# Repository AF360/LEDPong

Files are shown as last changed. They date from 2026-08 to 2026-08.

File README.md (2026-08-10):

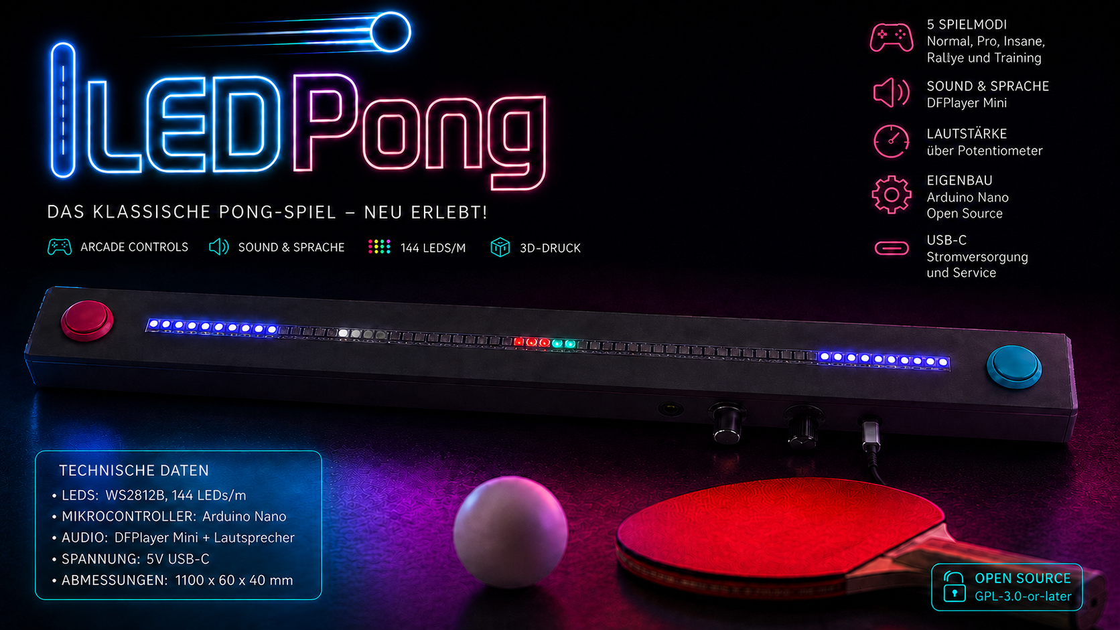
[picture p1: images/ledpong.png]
LEDPong


# LEDPong

LEDPong ist eine moderne Interpretation des klassischen Pong-Spiels.
Gespielt wird nicht auf einem Bildschirm, sondern auf einem **1 m langen LED-Strip mit 144 adressierbaren WS2812B-LEDs**.

Zwei Spieler versuchen, den als leuchtende LED dargestellten Ball mit ihren Arcade-Tastern im richtigen Moment zurückzuspielen. Mehrere Schwierigkeitsstufen und Spielmodi, Sprachansagen, Soundeffekte und eine Lautstärkeregelung ergänzen das Spiel.

## Spielmodi

1. **Anfänger-Modus** (große Rückschlagzonen, niedrige Geschwindigkeit und Beschleunigung)
2. **Profi-Modus** (kleinere Rückschlagzonen, höhere Geschwindigkeit und Beschleunigung)
3. **Insane-Modus** (stark verkleinerte Rückschlagzonen und höhere Beschleunigug)
4. **Rallye-Modus** (nach jeweils drei erfolgreichen Rückschlägen werden beide Rückschlagzonen verkleinert)
5. **Training-Modus** (ein Spieler tritt auf der grünen Seite gegen den Arduino an)

## Besonderheiten

- 🎮 Zwei Arcade-Taster für die Spieler
- 🔊 Sprachansagen und Soundeffekte über DFPlayer Mini
- 🌈 144 adressierbare WS2812B-LEDs
- 🎚 Lautstärkeregelung per Potentiometer
- 🎛 5-fach-Moduswahlschalter zur Auswahl fünf unterschiedlicher Spielmodi
- 🖨 Druckfertige 3D-Modelle für Gehäuse- und Bedienelemente
- 🔧 Vollständige Aufbau-, Verdrahtungs- und Bedienungsdokumentation

## Dokumentation und Dateien

- **[Dokumentation](docs/README.md)** – Stückliste, Aufbauanleitung, Verdrahtungsplan und Bedienungsanleitung
- **[Firmware](firmware/README.md)** – Arduino-Sketch und benötigte Bibliotheken
- **[Audiodateien](audio/README.md)** – Sprachansagen und Soundeffekte
- **[Gehäuse und 3D-Druck](gehäuse/README.md)** – Hinweise zum Kabelkanal und zu den STL-Dateien
- **[Release V1.1.1](https://github.com/AF360/LEDPong/releases/tag/V1.1.1)** – aktueller, stabiler und vollständiger Veröffentlichungsstand

## Lizenz und Danksagungen

LEDPong wird unter der **GNU General Public License v3.0 oder später** veröffentlicht.
Weitere Informationen zu den ursprünglichen Projekten und Mitwirkenden befinden sich in **[AUTHORS.md](AUTHORS.md)**.

### Das fertige LEDPong, hier als weiße Version mit 144er Light-Strip:
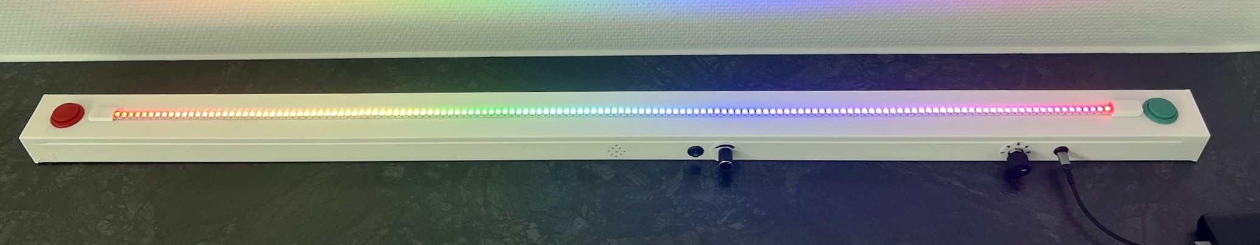
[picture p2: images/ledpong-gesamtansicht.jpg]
LEDPong1

Gesamtansicht, LED-Rainbow während des Systemstarts

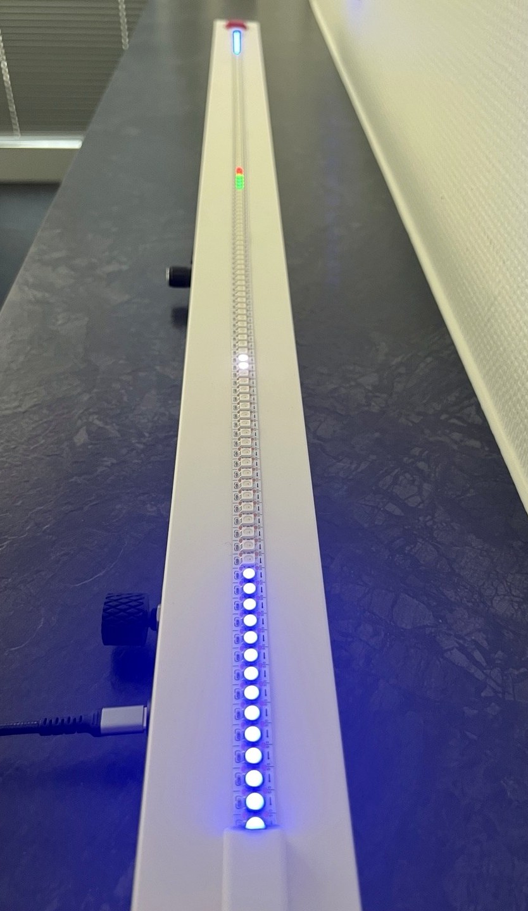
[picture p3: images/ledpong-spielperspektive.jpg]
LEDPong2

Spielperspektive mit Rückschlagzone, Ball in Bewegung und Score-Anzeige in der Mitte

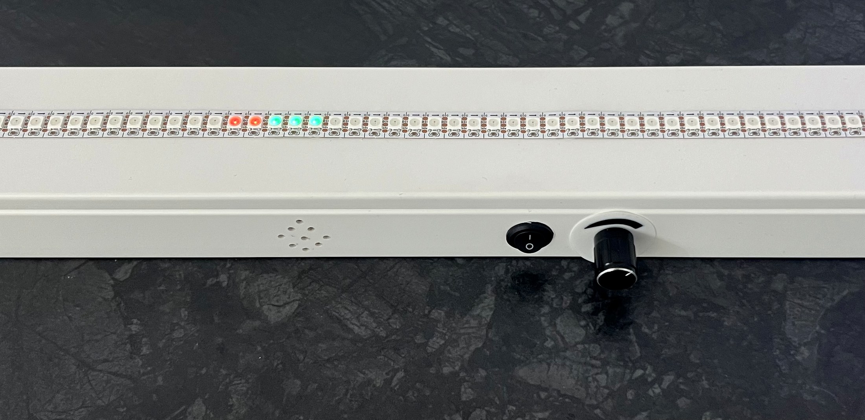
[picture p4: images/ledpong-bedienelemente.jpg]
LEDPong3

Score-Anzeige und Lautstärke-Regler sowie LS-Ein-/Ausschalter

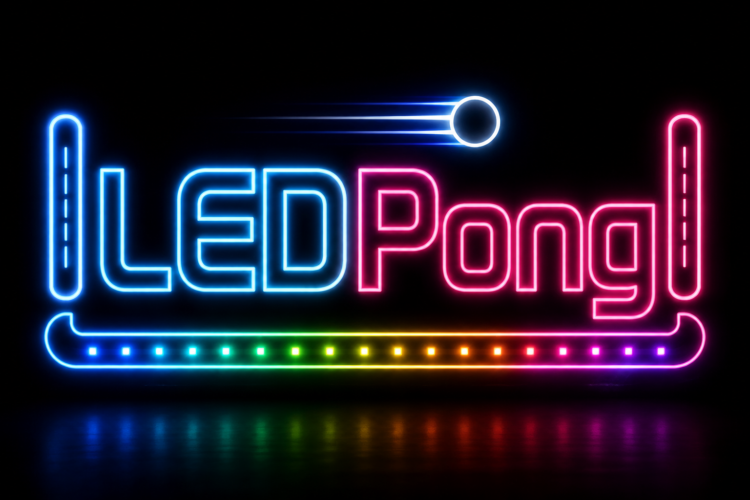
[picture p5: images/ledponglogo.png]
LEDPong-Logo


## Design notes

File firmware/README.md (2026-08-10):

# Firmware

Für den LEDPong-Sketch (LEDPong_v1.1.0.ino) müssen zusätzliche folgende Arduino-Bibliotheken in der Arduino-IDE installiert werden:

- FastLED by Daniel Garcia (verwendet: Version 3.10.5)
- DFRobotDFPlayerMini by DFRobot (verwendet: Version 1.0.6)

## Spielerfarben anpassen

Standardmäßig verwendet LEDPong **Rot** für Spieler 1 und **Grün** für Spieler 2. Die Farben werden im Sketch über folgende Zeile festgelegt:

```cpp
byte playerColor[] = {0, 96};    // Rot & Grün
```

Die Werte entsprechen dem Farbton (`Hue`) des von FastLED verwendeten HSV-Farbmodells. Einige geeignete Beispiele:

| Farbe | Wert |
|---|---:|
| Rot | `0` |
| Gelb | `64` |
| Grün | `96` |
| Hellblau / Türkis | `128` |
| Blau | `160` |
| Violett | `192` |

Beispiel für **Gelb und Hellblau**:

```cpp
byte playerColor[] = {64, 128};
```

Die Rückschlagzonen verwenden standardmäßig den Wert `160` (Blau). Dieser Farbwert sollte daher möglichst **nicht als Spielerfarbe** verwendet werden, damit Spieler- und Rückschlagzonen eindeutig unterscheidbar bleiben.

Werden andere Tastenfarben verwendet, können zusätzlich die entsprechenden alternativen Sprachansagen aus dem Verzeichnis `audio/alternative-Tastenfarben` verwendet werden.

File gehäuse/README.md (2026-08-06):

# Gehäuse und 3D-Druck

Als Gehäuse wird ein handelsüblicher 2 m Kabelkanal mit den Massen 60 x 40 mm verwendet und auf ca. 1100-1150 mm abgelängt.
Bezugsquelle z.B. https://www.bauhaus.info/kabelkanaele/kabelkanal/p/22835297 (in Baumärkten meistens nur in weiß oder grau erhältlich)
oder bei Amazon auch in schwarz: https://www.amazon.de/dp/B0F6V747F6 
(Aufpassen: Bei Amazon werden häufig 2x 1M Stücke angeboten, wir brauchen aber mindestens 1,10 Meter am Stück!)

Die .STL-Dateien für passende Endkappen, LED-Abdeckkappen sowie Wahlschalter-Kappe & Skalen befinden sich im Unterordner "stl"

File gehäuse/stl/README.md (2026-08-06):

# STL-Dateien

In diesem Verzeichnis befinden sich die druckfertigen 3D-Modelle für LEDPong.

- **[Endkappe 60 × 40 mm, geschlossen](LEDPong-Endkappe-60x40.stl)**  
  Geschlossene Endkappe für das gegenüberliegende Ende des Kabelkanals.

- **[Endkappe 60 × 40 mm mit USB-C-Einlass](LEDPong-Endkappe-mit-USB-60x40.stl)**  
  Endkappe zur Aufnahme der USB-C-Panelbuchse.

- **[Abdeckkappe für die Enden des LED-Strips](LEDStrip-Abdeckkappe.stl)**  
  Verdeckt die Anschlussleitungen und Bohrungen an den Enden des LED-Strips. Das Modell wird für beide Seiten verwendet.

- **[Zeigerknopf für den Moduswahlschalter](Modusauswahlknopf-mit-Zeiger.stl)**  
  Drehknopf mit Zeiger zur Auswahl der fünf Spielmodi.

- **[Schalttafel für die Modusauswahl 1–5](Schalttafel-1-2-3-4-5.stl)**  
  Beschriftete Skala für den 5-fach-Moduswahlschalter.

- **[Schalttafel für die Lautstärke](Schalttafel-Lautstärke.stl)**  
  Beschriftete Skala für das Lautstärke-Potentiometer.

## Druckhinweise

Die Bauteile können mit gängigen Filamenten wie **PLA** oder **PETG** gedruckt werden.

Für die zweifarbigen Schalttafeln kann während des Drucks ein Filamentwechsel vorgenommen oder ein Mehrfarbdrucksystem verwendet werden.

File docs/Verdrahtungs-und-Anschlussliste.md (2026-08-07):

# LEDPong Verdrahtung 

## Arduino Nano

| Nano-Pin | Ziel | Elektrische Funktion |
|---|---|---|
| 5V | gemeinsamer geregelter +5V-Bus | Versorgung |
| GND | gemeinsamer GND-Bus | Masse |
| D2 | Taster Spieler 0 → GND | `INPUT_PULLUP`, aktiv LOW |
| D3 | Taster Spieler 1 → GND | `INPUT_PULLUP`, aktiv LOW |
| D4 | DFPlayer TX | SoftwareSerial RX des Nano |
| D5 | über 1 kΩ zu DFPlayer RX | SoftwareSerial TX des Nano |
| D6 | WS2812B DIN | LED-Datensignal |
| D7 | Drehschalter Position 1 → GND über COM | Modus Normal, aktiv LOW |
| D8 | Drehschalter Position 2 → GND über COM | Modus Pro, aktiv LOW |
| D9 | Drehschalter Position 3 → GND über COM | Modus Insane, aktiv LOW |
| D10 | Drehschalter Position 4 → GND über COM | Modus Rallye, aktiv LOW |
| D11 | Drehschalter Position 5 → GND über COM | Modus Training, aktiv LOW |
| A0 | unbeschaltet | Rauschquelle für `randomSeed(analogRead(0))` |
| A1 | Schleifer des 10-kΩ-Potis | Lautstärke; GND = Minimum, +5V = Maximum |

## DFPlayer Mini

| DFPlayer-Pin | Ziel |
|---|---|
| VCC | +5V |
| GND | gemeinsamer GND |
| TX | Nano D4 |
| RX | Nano D5 über 1 kΩ Serienwiderstand |
| SPK+ | über SPST-Ein/Aus-Schalter zum Lautsprecher + |
| SPK− | direkt zum Lautsprecher − |

Der Lautsprecherausgang ist gebrückt. Weder SPK+ noch SPK− darf mit GND verbunden werden.

## WS2812B-Strip

- 1 Meter, 144 LEDs (`NUM_LEDS = 144`)
- +5V an geregelte 5V-Versorgung
- GND an gemeinsame Masse
- DIN an Nano D6 (Achtung: Die WS2812B Strips haben eine Datenrichtung! Der Anschluss des Arduino muss am Eingang des Strips erfolgen.)
- Stromversorgung passend zur tatsächlichen Helligkeit dimensionieren

## Bedienelemente

- Spieler-0-Taster: Nano D2 ↔ Taster ↔ GND
- Spieler-1-Taster: Nano D3 ↔ Taster ↔ GND
- 5-fach-Drehschalter: Positionen 1–5 an D7–D11, gemeinsamer Anschluss COM an GND
- Lautstärke-Poti 10 kΩ: Endanschlüsse an GND und +5V, Schleifer an A1
- Speaker-Mute: SPST-Schalter in Reihe zwischen DFPlayer SPK+ und Lautsprecher+

## Versorgung

- Eine gemeinsame geregelte +5V-Quelle
- Gemeinsame Masse für Nano, DFPlayer, LED-Strip, Taster, Drehschalter und Poti
- 100 nF und 100 µF parallel zwischen +5V und GND nahe der Steuerelektronik
- Externe +5V an den 5V-Pin des Nano, nicht an VIN
- Keine zweite USB-Stromquelle gleichzeitig anschließen

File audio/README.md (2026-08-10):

# Audiodateien

Die mit LEDPong ausgelieferten Sprachansagen und Soundeffekte wurden speziell für dieses Projekt erstellt.
Die Audiodateien können bei Bedarf auch durch eigene Dateien ersetzt werden. Damit die Firmware weiterhin funktioniert, müssen die Dateinamen und die Ordnerstruktur dabei unverändert bleiben.

## Aktuelle Belegung

| Datei | Verwendung | gesprochener Text |
|---|---|---|
| 001.mp3 | Spiel beginnt | |
| 002.mp3 | Ball getroffen | |
| 003.mp3 | Ball verfehlt | |
| 004.mp3 | Aufschlag | |
| 005.mp3 | Spiel gewonnen | |
| 010.mp3 | Begrüßung | "Hallo. Willkommen zu Pong" |
| 011.mp3 | Bedienhinweis | "Helligkeit mit roter Taste einstellen" |
| 012.mp3 | Bedienhinweis | "Spiel mit grüner Taste starten" |
| 020.mp3 | Modus Normal | "Du hast den Anfänger-Modus ausgewählt" |
| 021.mp3 | Modus Pro | "Du hast den Profi-Modus ausgewählt" |
| 022.mp3 | Modus Insane | "Du hast den Insane-Modus ausgewählt" |
| 023.mp3 | Rallye-Modus | "Du hast den Rallye-Modus ausgewählt" |
| 024.mp3 | Training-Modus | "Du hast den Training-Modus ausgewählt" |

## Ordnerstruktur auf der microSD-Karte
Die Firmware erwartet dreistellig nummerierte Dateien im Ordner `01` der microSD-Karte des DFPlayerMini.

```text
01/
├── 001.mp3
├── 002.mp3
├── 003.mp3
├── 004.mp3
├── 005.mp3
├── 010.mp3
├── 011.mp3
├── 012.mp3
├── 020.mp3
├── 021.mp3
├── 022.mp3
├── 023.mp3
└── 024.mp3
```

## Alternative Hinweisdateien für andere Tastenfarben

| Datei | Verwendung | gesprochener Text |
|---|---|---|
| 011-gelb.mp3 | Bedienhinweis | "Helligkeit mit gelber Taste einstellen" |
| 011-gruen.mp3 | Bedienhinweis | "Helligkeit mit grüner Taste einstellen" |
| 011-blau.mp3 | Bedienhinweis | "Helligkeit mit blauer Taste einstellen" |
| 012-gelb.mp3 | Bedienhinweis | "Spiel mit gelber Taste starten" |
| 012-blau.mp3 | Bedienhinweis | "Spiel mit blauer Taste starten" |
| 012-rot.mp3 | Bedienhinweis | "Spiel mit roter Taste starten" |

### Andere Tasten- und Spielerfarben verwenden

Die Farbe der Arcade-Taster und die Spielerfarben der LEDs sind technisch unabhängig voneinander. Werden andere Tasterfarben als Rot und Grün verwendet, müssen daher zwei Dinge angepasst werden:

1. Die gewünschten LED-Spielerfarben im Sketch über `playerColor[]` einstellen, siehe dazu auch [Firmware/README.md](/firmware/README.md).
2. Die passenden Sprachansagen aus `audio/alternative-Tastenfarben` auswählen und als `011.mp3` bzw. `012.mp3` auf die microSD-Karte kopieren.

Beispiel für einen **gelben linken Taster** und einen **blauen rechten Taster**:

```cpp
byte playerColor[] = {64, 128};    // Gelb & Hellblau
```

Dazu:

- `011-gelb.mp3` als `011.mp3` auf die Speicherkarte kopieren.
- `012-blau.mp3` als `012.mp3` auf die Speicherkarte kopieren.

Für den rechten Spieler wird im Beispiel bewusst der Farbwert `128` (Hellblau/Türkis) verwendet. Dadurch bleibt die Spielerfarbe deutlich von den blauen Rückschlagzonen mit dem Farbwert `160` unterscheidbar, obwohl physisch ein blauer Arcade-Taster verwendet wird.

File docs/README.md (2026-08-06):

# Dokumentation

In diesem Verzeichnis befinden sich alle Unterlagen für den Aufbau, die Verkabelung und die Bedienung von LEDPong.

- **[Stückliste](Stückliste.md)**  
  Übersicht aller benötigten elektronischen, mechanischen und gedruckten Komponenten.

- **[Aufbauanleitung](Aufbauanleitung.md)**  
  Schrittweise Anleitung zur Vorbereitung, Montage, Verkabelung und Inbetriebnahme.

- **[Grafischer Verdrahtungs- und Anschlussplan](Grafischer-Verdrahtungs-und-Anschlussplan.jpg)**  
  Anschlussplan als direkt betrachtbare Grafikdatei.

- **[Bearbeitbarer Verdrahtungs- und Anschlussplan](Grafischer-Verdrahtungs-und-Anschlussplan.drawio)**  
  Quelldatei des Anschlussplans im Draw.io-Format. Sie kann mit [draw.io](https://www.drawio.com) oder der Draw.io-Desktop-App geöffnet und bearbeitet werden.

- **[Verdrahtungs- und Anschlussliste](Verdrahtungs-und-Anschlussliste.md)**  
  Übersicht aller Leitungsverbindungen, Pins und Anschlüsse.

- **[Bedienungsanleitung](Bedienungsanleitung.md)**  
  Beschreibung der Bedienelemente, Spielmodi und Spielregeln.

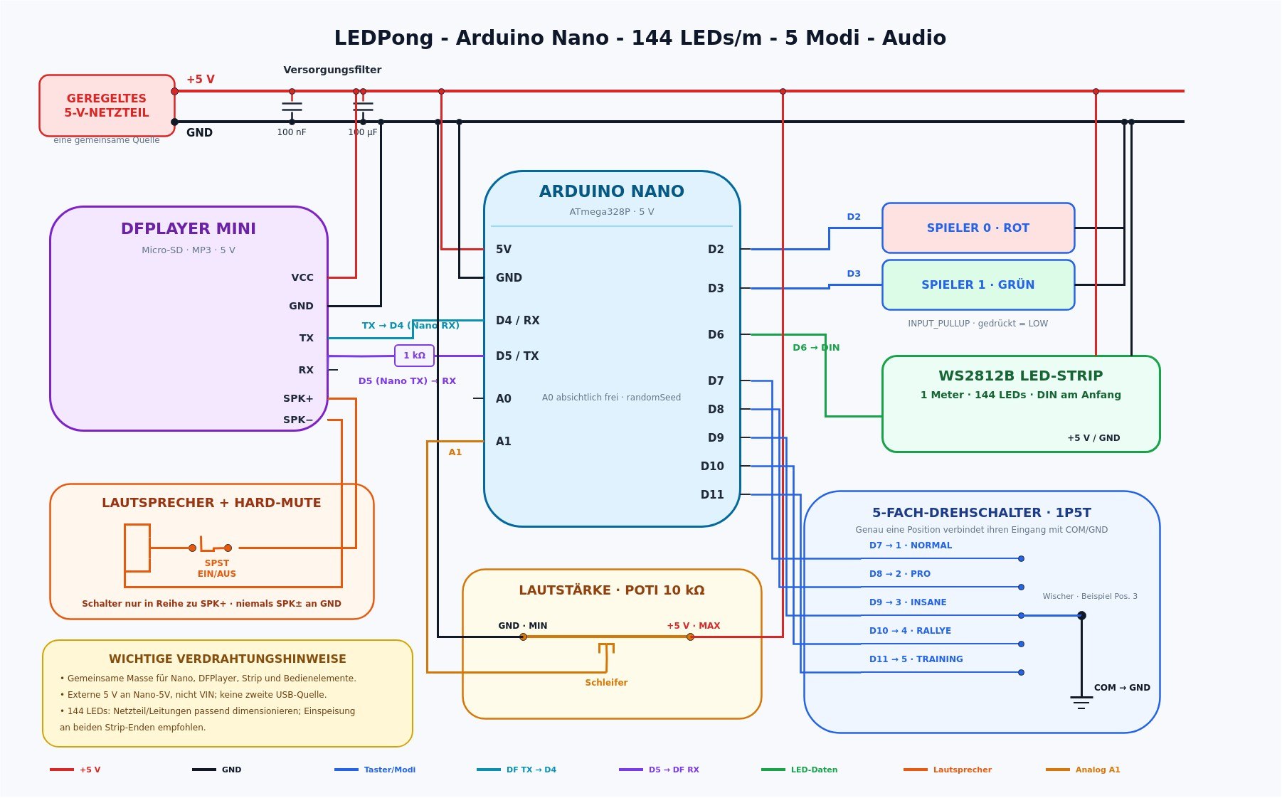
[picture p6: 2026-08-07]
docs/Grafischer-Verdrahtungs-und-Anschlussplan.jpg

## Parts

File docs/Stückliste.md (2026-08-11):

# Stückliste (Bill of Materials)

## Elektronik

  ---------------------------------------------------------------------------------------------------
             Menge Bauteil                     Bezugsquelle                          Einzelpreis
  ---------------- --------------------------- ------------------------------------- ----------------
                1× Arduino Nano V3             https://www.amazon.de/dp/B0GSJCL116   EUR 4,49
                   (ATmega328P, CH340)         

                1× DFPlayer Mini MP3-Modul     https://www.amazon.de/dp/B0DGPW88GF   EUR 3,37

                1× MicroSDHC-Karte 4 GB (für   https://www.amazon.de/dp/B008X6A3WS   EUR 4,90
                   Sprachansagen und Sounds)   

                1× Mini-Lautsprecher, 3 W / 8  https://www.amazon.de/dp/B09PL6XFHB   EUR 1,90
                   Ω                           

                1× WS2812B LED-Strip, 144      https://www.amazon.de/dp/B09N97D1J3   EUR 14,99
                   LEDs/m, 1 m (schwarz)       

                   alternativ: WS2812B         https://www.amazon.de/dp/B09N992SZC   EUR 13,99
                   LED-Strip, 144 LEDs/m, 1 m                                        (alternativ)
                   (weiß)                      

                1× Drehpotentiometer 10 kΩ     https://www.amazon.de/dp/B093DRBG3X   EUR 0,99
                   linear                      

                1× 5-Positionen-Drehschalter   https://www.amazon.de/dp/B0DM5TKYP9   EUR 3,15
                   (1-polig)                   

                2× Arcade-Taster Ø30 mm (1×    https://www.amazon.de/dp/B01MRWL6DW   EUR 1,00
                   rot, 1× grün)                                                     (2 Stück benötigt)

                1× USB-C-Einbaubuchse          https://www.amazon.de/dp/B0F2SFVNQT   EUR 0,77
                   (2-polig) für               
                   Stromversorgung             

                1× USB-C 3.0                   https://www.amazon.de/dp/B0FSPYQZTW   EUR 9,99
                   Panel-Mount-Verlängerung    
                   (Arduino-Serviceport)       

                1× 2-poliger Wippschalter      https://www.amazon.de/dp/B0H68W68SG   EUR 0,70
                   (Lautsprecher Ein/Aus)      
    ---------------------------------------------------------------------------------------------------

## Passive Bauteile

  --------------------------------------------------------------------------------------------------
             Menge Bauteil                 Bezugsquelle                               Einzelpreis
  ---------------- ----------------------- ---------------------------------------------------------
                1× Widerstand 1 kΩ         https://www.amazon.de/gp/aw/d/B0G8F2S5DW   EUR 0,06

                1× Elektrolytkondensator   https://www.amazon.de/dp/B0FB8Y5HYT        EUR 0,26
                   100 µF                  

                1× Keramikkondensator      https://www.amazon.de/Monolithische-       EUR 0,05
                   100 nF                  Mehrschichtiger-Kondensatoren-
                                           verschiedene-elektronische/dp/B0GWMVTD1H
  --------------------------------------------------------------------------------------------------

## Gehäuse

  --------------------------------------------------------------------------------------------------
             Menge Bauteil                 Bezugsquelle                            Einzelpreis
  ---------------- ----------------------  --------------------------------------- -----------------
                1× Kabelkanal 60 × 40 mm,  https://www.bauhaus.info/kabelkanaele/  EUR 4,85
                   Länge ca. 1100 mm       kabelkanal/p/22835297
                   (weiß)                 

                   alternativ: Kabelkanal https://www.amazon.de/dp/B0F6V747F6      EUR 14,90
                   60 × 40 mm (schwarz)                                            (alternativ)
  --------------------------------------------------------------------------------------------------

## Zusätzlich benötigt

-   3D-gedruckte Bauteile (Endkappen, Drehknopf, Modus-Skala, Einleger
    usw.)
-   Litze (empfohlen AWG20 bis AWG18 für die Spannungsversorgung)
-   Lötzinn
-   Lötkolben
-   Schrumpfschlauch
-   Kabelbinder oder Klebepads (optional)
-   Schrauben für Lautsprecher und Befestigungsteile
-   USB-C-Netzteil oder Powerbank (5V, mindestens 3A empfohlen)

## Gesamtkosten

Je nach Bezugsquelle liegen die Materialkosten bei ungefähr **50
€**, sofern Werkzeug und 3D-Drucker bereits vorhanden sind.

> **Hinweis:** Die genannten Bezugsquellen dienen lediglich als
> Beispiele. Gleichwertige oder kompatible Komponenten anderer
> Hersteller können selbstverständlich ebenfalls verwendet werden.

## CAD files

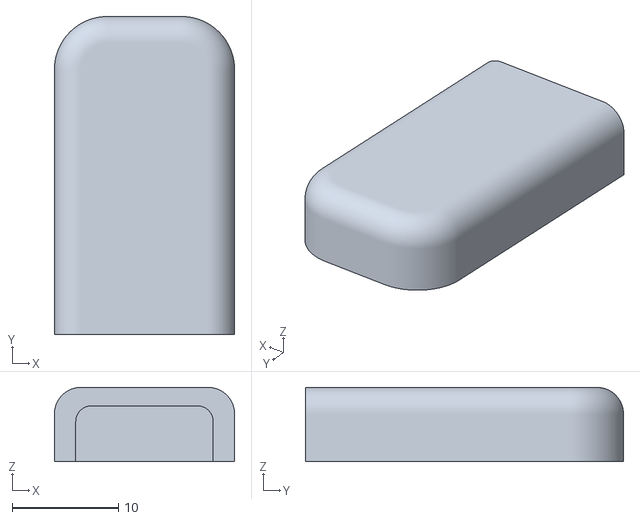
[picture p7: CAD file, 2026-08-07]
gehäuse/stl/LEDStrip-Abdeckkappe.stl
17.0 x 30.0 x 7.00

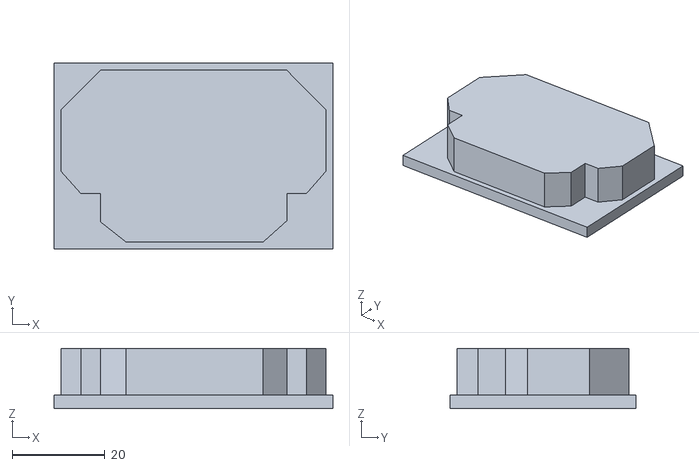
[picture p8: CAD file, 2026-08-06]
gehäuse/stl/LEDPong-Endkappe-60x40.stl
60.0 x 40.0 x 13.0

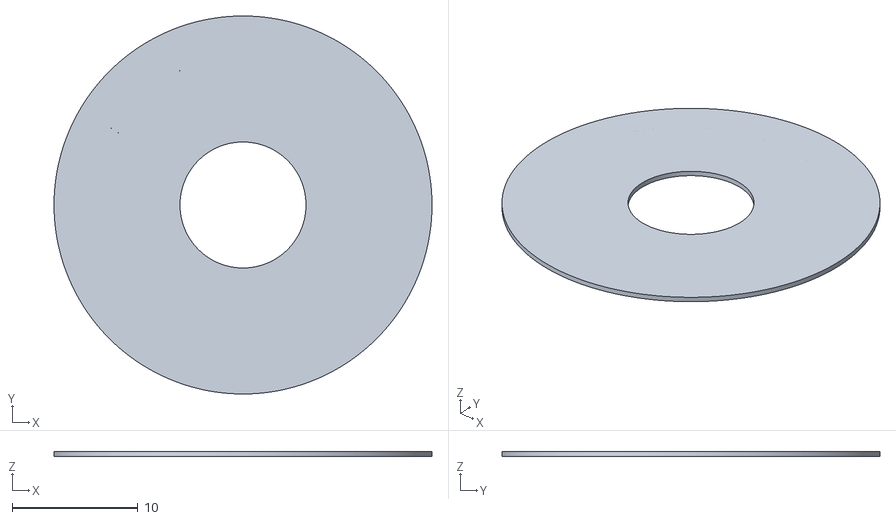
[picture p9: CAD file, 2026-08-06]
gehäuse/stl/Schalttafel-Lautstärke.stl
30.0 x 30.0 x 0.4

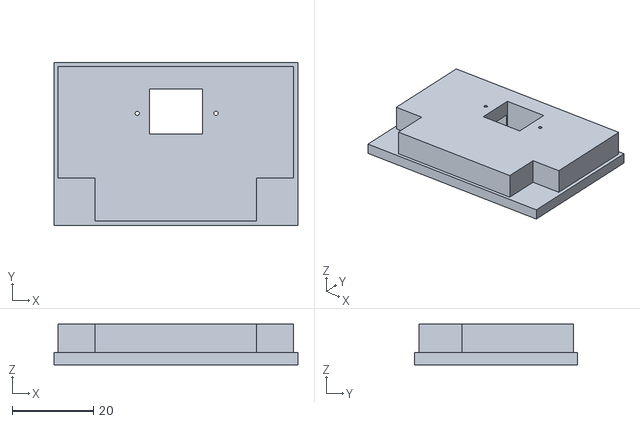
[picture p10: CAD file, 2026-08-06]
gehäuse/stl/LEDPong-Endkappe-mit-USB-60x40.stl
60.0 x 40.0 x 10.0

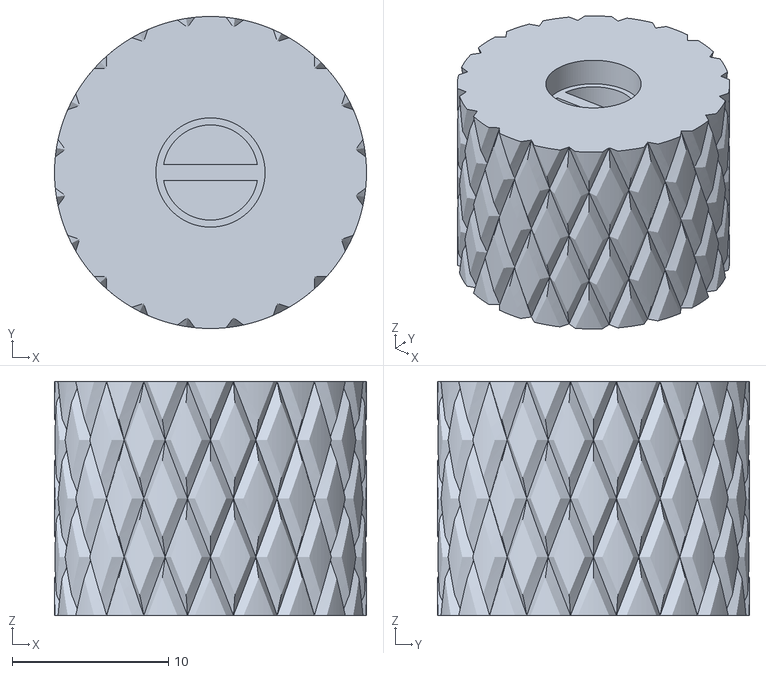
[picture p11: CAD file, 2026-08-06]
gehäuse/stl/Modusauswahlknopf-mit-Zeiger.stl
20.0 x 20.0 x 15.0

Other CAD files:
gehäuse/stl/Schalttafel-1-2-3-4-5.stl

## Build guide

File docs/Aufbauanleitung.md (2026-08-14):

# LEDPong Aufbauanleitung

## 1. Komponenten vorbereiten

Alle benötigten Komponenten und Werkzeuge gemäß Stückliste bereitlegen und die benötigten 3D-Druckteile ausdrucken.
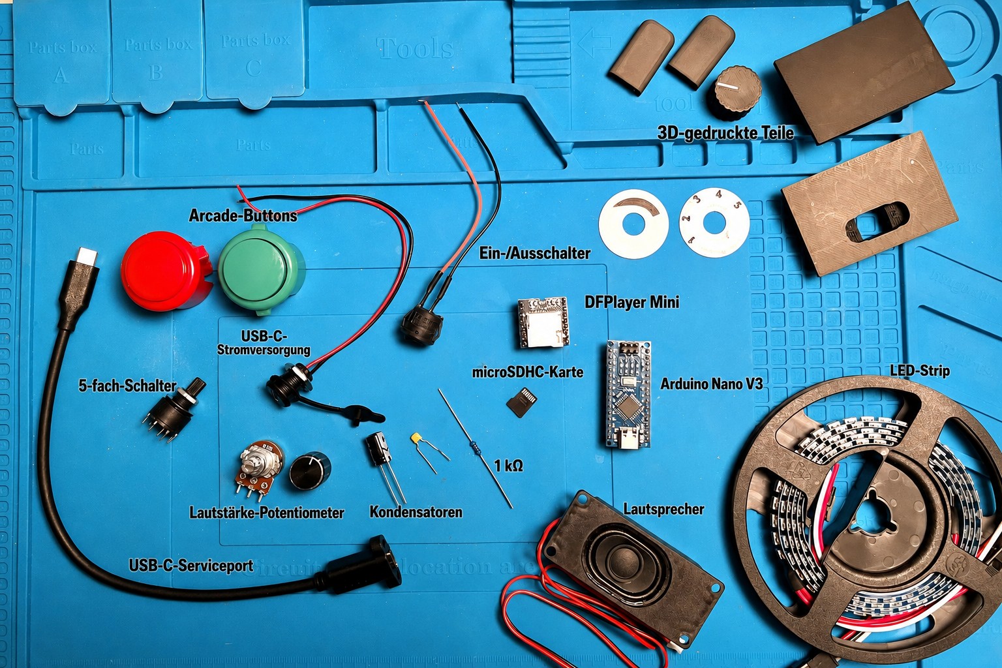
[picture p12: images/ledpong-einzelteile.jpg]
LEDPong-Einzelteile


## 2. Arduino Nano vorbereiten

Die Arduino IDE installieren und starten. Anschließend den Sketch `LEDPong_v1.1.0.ino` aus dem Verzeichnis `firmware` dieses Repositorys öffnen.

Den Arduino Nano per USB mit dem Computer verbinden.

In der Arduino IDE folgende Einstellungen vornehmen:

- **Tools → Board → Arduino AVR Boards → Arduino Nano**
- **Tools → Port → passenden Port auswählen**

Der richtige Port ist normalerweise derjenige, der nach dem Anschließen des Arduino Nano neu in der Liste erscheint.

Über das Bibliotheks-Symbol am linken Fensterrand die Bibliotheksverwaltung öffnen und folgende Bibliotheken installieren:

- **FastLED** von Daniel Garcia  
  Getestete Version: 3.10.5
- **DFRobotDFPlayerMini** von DFRobot  
  Getestete Version: 1.0.6

Danach den Sketch über **Sketch → Verify/Compile** überprüfen und kompilieren. Wenn keine Fehler auftreten, den Sketch über **Sketch → Upload** auf den Arduino Nano übertragen.

Der Arduino Nano ist damit für den Einbau vorbereitet.

> **Tipp:** Falls der Upload bei einem Nano-Klon fehlschlägt, unter **Tools → Processor** testweise **ATmega328P (Old Bootloader)** auswählen.

## 3. MicroSDHC-Karte vorbereiten

Die MicroSDHC-Karte über einen Kartenleser mit dem Computer verbinden und mit dem Dateisystem **FAT32** formatieren.

Im Hauptverzeichnis der Karte einen Ordner mit dem Namen `01` anlegen. Anschließend die Audiodateien `001.mp3` bis `024.mp3` in diesen Ordner kopieren.

Die Karte danach sicher auswerfen und in den DFPlayer Mini einsetzen.

> **Tipp:** Für eine möglichst hohe Kompatibilität sollte eine kleine MicroSDHC-Karte verwendet werden. Die in der Stückliste empfohlene 4-GB-Karte funktioniert zuverlässig. Größere Karten können je nach Hersteller und Formatierung Probleme verursachen.

## 4. Kabelkanal zuschneiden

Den Kabelkanal auf eine Länge von etwa **1.100 bis 1.150 mm** kürzen.

Die Schnittkanten anschließend entgraten.

## 5. Bohrungen im Deckel markieren

Den LED-Strip mittig auf den Deckel des Kabelkanals legen, zunächst jedoch noch nicht festkleben.

Die Positionen der Anschlussleitungen an beiden Enden des LED-Strips auf dem Deckel markieren.

An beiden Enden des Deckels außerdem die Positionen der beiden Arcade-Taster anzeichnen.

Vor dem Bohren prüfen, ob unterhalb der markierten Positionen ausreichend Platz für Taster, Leitungen und Befestigungsteile vorhanden ist.

## 6. Seitliche Bohrungen markieren und herstellen

Die benötigten Bohrdurchmesser der verwendeten Schalter und Bedienelemente mit einer Schieblehre ermitteln.

Anschließend die Positionen für folgende Komponenten an der Seite des Kabelkanals festlegen und markieren:

- Moduswahlschalter
- USB-C-Spannungszuführung
- Lautstärke-Potentiometer
- Lautsprecher-Ein-/Ausschalter

Die Bohrungen mit den jeweils passenden Durchmessern herstellen und entgraten.

Etwa in der Mitte des Kabelkanals für den Lautsprecher neun kleine Bohrungen mit ungefähr **3 mm Durchmesser** stern- oder rautenförmig anordnen.

Der Lautsprecher wird später von innen hinter diese Öffnungen geklebt, damit der Schall möglichst ungehindert nach außen gelangen kann.

## 7. Verkabelung vorbereiten

Die USB-C-Panelbuchse in die Endkappe einsetzen und verschrauben beziehungsweise einkleben.

Die Länge des Anschlusskabels der USB-C-Panelbuchse bestimmt die spätere Position des Arduino Nano innerhalb des Kabelkanals. Die Panelbuchsen sind beispielsweise mit 0,3 m, 0,5 m oder 0,9 m Kabellänge erhältlich.

Von der vorgesehenen Arduino-Position aus die benötigten Leitungslängen zu folgenden Komponenten ermitteln:

- Arcade-Taster
- Moduswahlschalter
- Lautstärke-Potentiometer
- Lautsprecher-Schalter
- LED-Strip
- DFPlayer Mini

Die Litzen passend ablängen und an die jeweiligen Schalter und Bedienelemente anlöten.

Anschließend die Komponenten in das Gehäuse einklipsen oder mit ihren Überwurfmuttern befestigen.

> **Tipp:** Für WAGO-221-Klemmen die Litzen etwa **11 mm** abisolieren. Für direkte Lötverbindungen reichen normalerweise **4 bis 5 mm**.

> **Tipp:** Potentiometer und Moduswahlschalter besitzen häufig eine kleine Verdrehsicherungsnase. Dafür kann von innen eine passende kleine Bohrung oder Vertiefung mit einem Bohrer beziehungsweise Fräser hergestellt werden.

## 8. LED-Strip montieren

Den LED-Strip mittig auf den Deckel des Kabelkanals kleben und seine Anschlussleitungen durch die zuvor gebohrten Öffnungen führen.

Die Enden des LED-Strips anschließend mit den gedruckten Abdeckkappen verdecken.

Die Abdeckkappen können verklebt oder verschraubt werden. Bei einer Verschraubung können die Schrauben von innen durch den Deckel in die Kappen geführt werden, damit außen keine Schraubenköpfe sichtbar sind.

> **Wichtig:** Darauf achten, dass sich der mit **DIN** gekennzeichnete Dateneingang des LED-Strips in der Nähe des Arduino Nano befindet. Der Arduino darf nicht versehentlich mit der Datenausgangsseite des Strips verbunden werden, sonst bleibt der Strip dunkel.

## 9. Spannungsversorgung verkabeln

Während der gesamten Verkabelung darf keine Spannungsquelle angeschlossen sein.

Die 5V- und GND-Leitungen der USB-C-Spannungszuführung mit den beiden vorgesehenen Kondensatoren verbinden. Beide Kondensatoren werden parallel zwischen **+5V** und **GND** angeschlossen.

Bei einem Elektrolytkondensator unbedingt auf die richtige Polarität achten:

- Pluspol an +5V
- Minuspol an GND

Anschließend eine sternförmige 5V-Verteilung und eine gemeinsame GND-Verteilung aufbauen. Dafür eignen sich beispielsweise WAGO-221-Klemmen.

An die gemeinsame 5V-Verteilung werden angeschlossen:

1. Arduino Nano, Pin `5V`
2. DFPlayer Mini, Pin `VCC`
3. LED-Strip, Anschluss `5V`
4. Lautstärke-Potentiometer, äußerer Anschluss

An die gemeinsame GND-Verteilung werden angeschlossen:

1. Arduino Nano, Pin `GND`
2. DFPlayer Mini, Pin `GND`
3. LED-Strip, Anschluss `GND`
4. Lautstärke-Potentiometer, äußerer Anschluss
5. Mittelkontakt des Moduswahlschalters
6. Massekontakt des roten Arcade-Tasters
7. Massekontakt des grünen Arcade-Tasters

Falls das verwendete DFPlayer-Mini-Modul zwei GND-Pins besitzt, sollten beide mit der gemeinsamen Masse verbunden werden.

Der mittlere Schleiferanschluss des Lautstärke-Potentiometers wird gemäß Anschlussplan mit dem Analogeingang `A1` des Arduino verbunden.

> **Tipp:** Wird die Lautstärke beim Drehen im Uhrzeigersinn leiser statt lauter, müssen die beiden äußeren Anschlüsse für 5V und GND am Potentiometer vertauscht werden.

> **Tipp:** Niemals mehrere Litzen gemeinsam in eine einzelne Federklemme stecken. Werden mehr Anschlüsse benötigt, eine weitere 3-fach- oder 5-fach-WAGO-221-Klemme über eine kurze Litzenbrücke anschließen. Für diese Brücke eignet sich beispielsweise AWG18- oder AWG20-Litze.

## 10. Lautsprecher anschließen

Den Lautsprecher direkt mit den Anschlüssen `SPK+` und `SPK-` des DFPlayer Mini verbinden.

Der Lautsprecher-Ein-/Ausschalter wird in Reihe in eine der beiden Lautsprecherleitungen eingeschleift.

Den Lautsprecher anschließend von innen hinter die stern- oder rautenförmig angeordneten 3-mm-Bohrungen kleben.

Dabei darauf achten, dass die Lautsprechermembran nicht mit Klebstoff in Berührung kommt und frei schwingen kann.

## 11. Signalverkabelung herstellen

Alle verbleibenden Leitungen gemäß Anschluss- und Pinbelegungsplan mit den korrekten Anschlüssen verbinden beziehungsweise verlöten.

Besonders auf folgende Verbindungen achten:

- Datenleitung des LED-Strips an den vorgesehenen Arduino-Pin
- RX- und TX-Verbindungen des DFPlayer Mini
- Signalleitungen der beiden Arcade-Taster
- Schleifer des Lautstärke-Potentiometers
- Kontakte des 5-fach-Moduswahlschalters

Nach Abschluss der Lötarbeiten alle Lötstellen auf Kurzschlüsse, lose Litzen und versehentliche Verbindungen zu benachbarten Kontakten prüfen.

## 12. Funktionstest durchführen

Vor dem ersten Einschalten mit einem Multimeter prüfen, ob zwischen **+5V** und **GND** kein Kurzschluss besteht.

Danach über ein geeignetes 5V-Netzteil oder eine ausreichend leistungsfähige Powerbank Spannung zuführen.

Folgende Funktionen testen:

- Startsequenz und Sprachausgabe
- LED-Strip
- roter und grüner Arcade-Taster
- Moduswahlschalter
- Lautstärke-Potentiometer
- Lautsprecher-Ein-/Ausschalter
- alle Spielmodi

Treten Probleme auf, die Spannungsversorgung sofort trennen und die Verkabelung erneut prüfen.

## 13. Gehäuse schließen

Die Endkappe mit der USB-C-Panelbuchse in den Kabelkanal einsetzen.

Das interne USB-Kabel mit dem USB-Anschluss des Arduino Nano verbinden und so verlegen, dass es nicht unter Spannung steht oder beim Schließen des Gehäuses eingeklemmt wird.

Alle Leitungen geordnet im Kabelkanal verstauen. Darauf achten, dass keine Litzen in den Bereich der Deckelrastung gelangen.

Anschließend den Deckel auf den Kabelkanal setzen und die zweite Endkappe montieren. Für zusätzlichen Halt empfiehlt sich die Fixierung des Deckels auf jeder Seite durch ein- bis zweimalige Umwicklung mit farblich passendem Klebeband (ich habe hier weißes Isolierband verwendet).

## 14. Fertig

LEDPong ist nun einsatzbereit.

Viel Spaß beim Spielen!

## Das fertige LEDPong:

LEDPong1
Gesamtansicht mit LED-Rainbow während des Startvorgangs

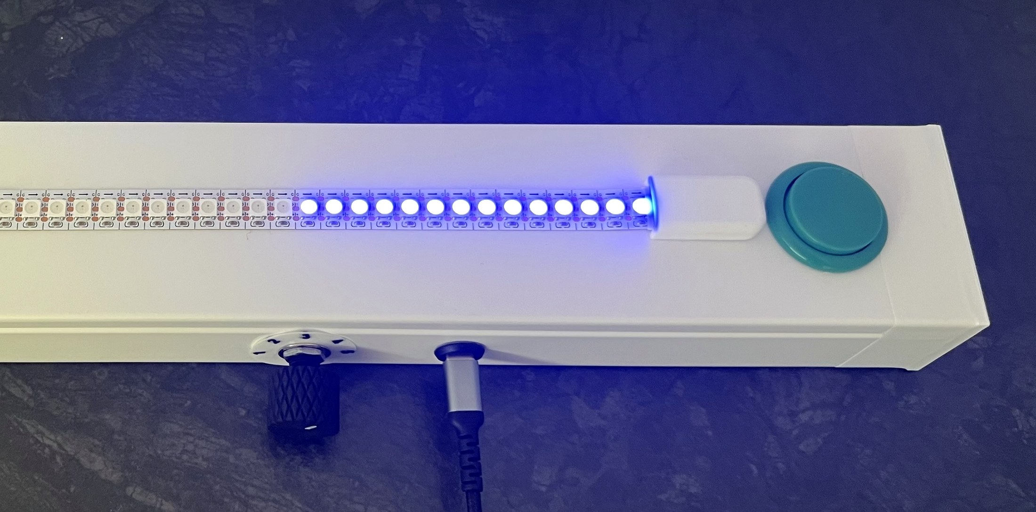
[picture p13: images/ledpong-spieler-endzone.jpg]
LEDPong2

Rückschlagzone, Abdeckkappe, 5-fach Moduswahlschalter, USB-C für Spannungsversorgung, hier mit Powerbank im Einsatz

LEDPong3
Score-Anzeige, Lautstärkeregler, Lautsprecher Ein-/Ausschalter

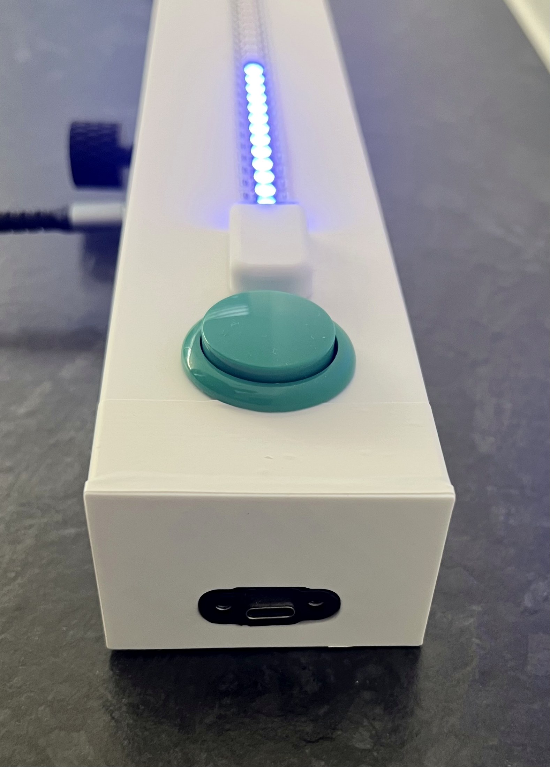
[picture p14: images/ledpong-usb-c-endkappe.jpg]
LEDPong4

Endkappe m. USB-C Serviceport zum flashen des Arduino, 30mm Arcade Button, LED-Strip-Abdeckkappe

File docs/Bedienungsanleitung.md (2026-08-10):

# LEDPong Bedienungsanleitung

## Einschalten und Moduswahl

Nach dem Einschalten beziehungsweise dem Anlegen der 5V-Versorgungsspannung startet LEDPong mit einem Regenbogeneffekt auf dem LED-Streifen. Anschließend folgen eine Willkommensansage und eine kurze Erläuterung zur Einstellung der LED-Helligkeit.

Mit dem 5-fach-Moduswahlschalter wird der gewünschte Spielmodus ausgewählt:

1. Anfänger-Modus
2. Profi-Modus
3. Insane-Modus
4. Rallye-Modus
5. Training-Modus 

Die Helligkeit der LEDs lässt sich durch mehrfaches Drücken der roten Taste in fünf Stufen durchschalten.

Ein Druck auf die grüne Taste startet den ausgewählten Modus.

## Spielstart

Beim ersten Match nach dem Einschalten wird der beginnende Spieler zufällig bestimmt. Am entsprechenden Ende des LED-Streifens leuchtet die Start-LED in der Farbe des Spielers.

Dieser Spieler muss seinen eigenen Taster drücken, um den Ball abzuschießen.

Nach einem Punkt eröffnet der Spieler die nächste Runde, der den Punkt erzielt hat. Nach einem vollständig beendeten Match beginnt im nächsten Match der vorherige Verlierer.

## Spielablauf

Der Ball bewegt sich als leuchtende LED über den Streifen.

Die blauen Bereiche an beiden Enden markieren die Rückschlagzone des jeweiligen Spielers. Je höher der eingestellte Schwierigkeitsgrad ist, desto kleiner wird diese Zone.

Nur innerhalb der blauen Rückschlagzone kann der Ball durch rechtzeitiges Drücken des eigenen Tasters erfolgreich zurückgespielt werden. Je näher der Ball am Ende des Spielfeldes getroffen wird, desto höher ist seine Rückspielgeschwindigkeit. Auch der gewählte Schwierigkeitsgrad beeinflusst die Ballgeschwindigkeit.

Mit jedem erfolgreichen Rückschlag wird der Ball zusätzlich etwas schneller. Dadurch steigt der Schwierigkeitsgrad im Verlauf einer Runde kontinuierlich an.

Erreicht der Ball die gegenüberliegende Rückschlagzone, muss der jeweilige Spieler seinen Taster im richtigen Moment betätigen. Erfolgt der Tastendruck innerhalb des erlaubten Bereichs, wird der Ball zurückgeschlagen und bewegt sich in die entgegengesetzte Richtung.

Wird zu früh oder zu spät gedrückt, geht der Ball verloren. Der Gegenspieler erhält einen Punkt, und in der Mitte des LED-Streifens wird der aktuelle Spielstand angezeigt. Anschließend beginnt die nächste Runde.

Das Match endet, sobald ein Spieler fünf Punkte erreicht hat.

## Rallye-Modus

Der Rallye-Modus beginnt mit den Spieleinstellungen und der Rückschlagzonengröße des Profi-Modus. Lediglich die maximal mögliche Ballgeschwindigkeit entspricht dem Insane-Modus. Nach jeweils drei erfolgreichen Rückschlägen werden beide Rückschlagzonen gleichzeitig kleiner. Die wegfallenden LEDs blinken zweimal rot, bevor das Spiel mit den kleineren Zonen weiterläuft. Nach jedem Punkt werden die Rückschlagzonen für die nächste Rallye auf ihre volle Größe zurückgesetzt.

## Training-Modus

Im Training-Modus spielt eine Person auf der grünen Seite gegen den Arduino auf der roten Seite. Die rote Taste behält vor dem Spiel ihre normale Funktion zur Helligkeitseinstellung; die grüne Taste startet das Training und dient anschließend als Spielertaste. Während des Matches wird die rote Spielertaste ignoriert.

Der Training-Modus verwendet die vollständigen Spieleinstellungen des Profi-Modus. Beim Aufrufen des Training-Modus wird der erste Aufschlag zufällig bestimmt. Beginnt Grün, wartet LEDPong auf den Aufschlag mit der grünen Taste. Beginnt Rot, schlägt der Arduino nach einer kurzen sichtbaren Pause automatisch auf. Nach einem Punkt schlägt wie in den anderen Spielmodi der Spieler auf, der den Punkt erzielt hat. Nach einem abgeschlossenen Match beginnt beim nächsten Start der vorherige Verlierer.

Der Arduino wählt seine Rückschlagposition innerhalb der roten Rückschlagzone zufällig. Durchschnittlich ungefähr jeden zehnten Rückschlag verfehlt er absichtlich, damit der menschliche Spieler Punkte erzielen kann. Das Match endet regulär bei fünf Punkten und verwendet die vorhandene Punkte- und Siegeranzeige.

## Lautstärke und Ton

Die Lautstärke wird über das Potentiometer eingestellt. Mit dem Ein-/Ausschalter für den Lautsprecher kann die Tonausgabe vollständig stummgeschaltet werden.

LEDPong

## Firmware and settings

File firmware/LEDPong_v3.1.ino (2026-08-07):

/*
  LEDPong v3.1
  =============

  Ein modernes Pong-Spiel auf einem 1 m langen adressierbaren LED-Strip
  mit Arcade-Tastern, Sound, Sprachansagen und fünf Betriebsarten.

  Copyright (C) 2026 Andreas Fatum

  Dieses Programm basiert auf:

  1. "1D Pong" von FlyingAngel (2020)
     https://www.hackster.io/flyingangel/1d-pong-85e965
     Die dort veröffentlichte Originalfassung steht unter der
     GNU General Public License, Version 3 oder später.

  2. "Pong mit Arduino" von Armin Duft (DH1DA)
     https://e-duft.de/pong-mit-arduino/
     Sound-erweiterte Fassung; Weiterverwendung und Veröffentlichung
     mit freundlicher Genehmigung von Armin Duft.

  Wesentliche LEDPong-Erweiterungen:

    - Unterstützung eines 1-m-WS2812B-Strips mit 144 LEDs
    - auf 144 LEDs skaliertes virtuelles 60-LED-Spielmodell
    - fünf Betriebsarten: Normal, Pro, Insane, Rallye und Training
    - 5-fach-Drehwahlschalter
    - Lautstärkeregelung über 10-kΩ-Potentiometer 
	- Ein-/Ausschalter für den Lautsprecher
    - stabilisierte DFPlayer-Mini-Ansteuerung
    - Sprachansagen und Soundeffekte
    - dynamisch schrumpfende Rückschlagzonen im Rallye-Modus
    - überarbeitete Pinbelegung und Hardware
    - USB-C-Serviceanschluss zum Flashen des Arduino Nano
    - 3D-gedruckte Gehäuse- und Bedienelemente

  Lizenz
  -------

  Dieses Programm ist freie Software: Sie können es unter den Bedingungen
  der GNU General Public License, wie von der Free Software Foundation
  veröffentlicht, weitergeben und/oder modifizieren; entweder gemäß
  Version 3 der Lizenz oder – nach Ihrer Wahl – jeder späteren Version.

  Dieses Programm wird in der Hoffnung bereitgestellt, dass es nützlich ist,
  jedoch OHNE JEDE GEWÄHRLEISTUNG; sogar ohne die implizite Gewährleistung
  der MARKTREIFE oder der EIGNUNG FÜR EINEN BESTIMMTEN ZWECK. Weitere
  Einzelheiten finden Sie in der GNU General Public License.

  Zusammen mit diesem Programm sollte eine Kopie der GNU General Public
  License bereitgestellt werden. Siehe <https://www.gnu.org/licenses/>.

  SPDX-License-Identifier: GPL-3.0-or-later
*/

#define FASTLED_INTERNAL           	// Disable version number message in FastLED library (looks like an error)
#include <FastLED.h>
#include "Arduino.h"
#include "SoftwareSerial.h"         // control mp3 Player via serial interface with 9600 baud
#include "DFRobotDFPlayerMini.h"    // mp3 Player

// ============================================================================
// Spielmodi und Spielparameter
// ============================================================================

enum GameMode {
  MODE_NORMAL = 0,
  MODE_PRO = 1,
  MODE_INSANE = 2,
  MODE_RALLYE = 3,
  MODE_TRAINING = 4,
  MODE_INVALID = 255
};

struct PongModeConfig {
  int startSpeed;
  int speedStep;
  int fastestSpeed;
  int boost0;
  int boost1;
  int boost2;
  unsigned char endZoneBase;
};

// Explicit prototypes are required in a single-file Arduino sketch because
// Arduino's automatic prototype generator can otherwise place declarations
// using GameMode/PongModeConfig before these custom types.
int modeAnnouncementTrack(GameMode mode);
PongModeConfig pongModeConfigFor(GameMode mode);

int modeAnnouncementTrack(GameMode mode) {
  return mode >= MODE_NORMAL && mode <= MODE_TRAINING ? 20 + static_cast<int>(mode) : 0;
}

PongModeConfig pongModeConfigFor(GameMode mode) {
  // start, step, limit, boost0, boost1, boost2, end zone size at 60 LEDs/m
  switch (mode) {
    case MODE_PRO:
      return {40, 2, 5, 15, 10, 5, 6};
    case MODE_INSANE:
      return {30, 3, 3, 10, 7, 3, 4};
    case MODE_RALLYE:
      // Pro settings with the Insane maximum speed.
      return {40, 2, 3, 15, 10, 5, 6};
    case MODE_TRAINING:
      return {40, 2, 5, 15, 10, 5, 6};
    case MODE_NORMAL:
    default:
      return {50, 1, 7, 20, 10, 5, 7};
  }
}

#define BASE_NUM_LEDS 60       		// Original game reference: 60 LEDs per metre
#define NUM_LEDS 144            		// Installed LEDs on the 1 m strip
#define PLAYER0  2              		// Button player 0
#define PLAYER1  3              		// button player 1
#define rxPin    4              		// mp3 serial interface RXD
#define txPin    5              		// mp3 serial interface TXD
#define DATA_PIN 6               		// LED data pin
#define MODE1    7                      // Pin for game mode 1
#define MODE2    8                      // Pin for game mode 2
#define MODE3    9                      // Pin for game mode 3
#define MODE4   10                      // Pin for game mode 4
#define MODE5   11                      // Pin for game mode 5
#define VOLUME_PIN A1             		// 10k potentiometer wiper for volume

const byte MODE_COUNT = 5;
const byte modePins[MODE_COUNT] = {MODE1, MODE2, MODE3, MODE4, MODE5};
const unsigned long MODE_DEBOUNCE_MS = 60;
const byte RALLYE_RETURNS_PER_SHRINK = 3;
const byte RALLYE_MIN_END_ZONE_BASE = 1;
const byte RALLYE_SHRINK_STEP_BASE = 1;
const byte RALLYE_FLASH_COUNT = 2;
const byte RALLYE_FLASH_ON_MS = 90;
const byte RALLYE_FLASH_OFF_MS = 70;
const int TRAINING_ARDUINO_PLAYER = 0;
const int TRAINING_HUMAN_PLAYER = 1;
const byte TRAINING_MISS_INTERVAL = 10;
const unsigned long TRAINING_AUTOMATIC_SERVE_DELAY_MS = 750UL;
const byte VOLUME_MIN = 1;
const byte VOLUME_MAX = 20;
const unsigned long START_TRACK_TIMEOUT_MS = 30000UL;

SoftwareSerial mySerial(rxPin,txPin);   // RX, TX

byte nfiles = 24;                       // highest mp3 file number currently used  
byte ifile  = 1;                        // number of file played next  
int brightness       =     105; 		    // default start brightness (war: 155)
byte playerBtnPin[] =   {PLAYER0, PLAYER1}; // Pins for buttons
byte volumeLevel    =       10; 		    // current DFPlayer volume 0 ... 30
int gameSpeedMin    =       50; 		    // min game-speed
int gameSpeedMax    =        5; 		    // max game-speed
int gameSpeedStep   =        1; 		    // increase speed when change direction
int ballSpeedMax    =        7; 		    // max ball-speed  (1 is maximum, larger values are slower)
int ballBoost0      =       20; 		    // superboost last position
int ballBoost1      =       10; 		    // boost second last position
int ballBoost2      =       5;  		    // boost third last position
byte playerColor[]  =  {0, 96}; 		    // red & green
int winRounds       =        5; 		    // number of points for winning the game
int endZoneSize     = (7L * NUM_LEDS + BASE_NUM_LEDS / 2) / BASE_NUM_LEDS; // set by applyModeSettings()
int endZoneColor    =      160; 		    // color endzone

// Definition System-Variables
boolean activeGame = false;             // true when game is active
boolean brightSet = true;               // set brightness at start of the game
unsigned long previousMoveMicros;       // timestamp of last ball move (microseconds)
unsigned long previousButtonMillis;     // timestamp of last button-press
unsigned long previousVolumeMillis;     // timestamp of last volume check
byte pendingVolumeLevel = 255;          // Mittelwertberechnung
byte pendingVolumeCount = 0;            // Mittelwertberechnung
byte previousVolumeLevel = 255;         // force initial volume update
int playerButtonPressed[2];             // ball-position where button was pressed; „-1“ button not pressed
int previousButtonPos = -1;             // position of last button-press
byte previousButtonColor;               // color of field for last Button-press
int playerScore[2];                     // current Score
byte playerStart;                       // who starts game
int gameSpeed;                          // current game-speed
int ballDir = 1;                        // direction, ball is moving (+/- 1)
int ballPos;                            // ball-position
int ballSpeed;                          // ball-speed (higher = slower)
int rallyeStartEndZoneSize;             // full end-zone size restored after each point
int rallyeMinimumEndZoneSize;           // smallest allowed Rallye end zone
int rallyeShrinkStep;                   // LEDs removed at each Rallye stage
int rallyeSuccessfulReturns = 0;        // successful returns in the current rally
int trainingHitPosition = -1;           // Arduino return position; -1 deliberately misses
GameMode selectedMode = MODE_NORMAL;
GameMode modeCandidate = MODE_INVALID;
unsigned long modeCandidateSince = 0;

CRGB leds[NUM_LEDS];                          // Define the array of LEDs
byte previousButtonBright = brightness / 2;   // bright of marked last position when button pressed
byte scoreDimBright       = brightness / 4;   // bright of dimmed score

// Explicit forward declarations.
// Arduino's automatic prototype generator may skip functions with a default argument.
void updateVolume(boolean forceUpdate = false);
GameMode readModeSwitchRaw();
void updateModeSelection();
void applyModeSettings(GameMode mode);
void announceMode(GameMode mode);
void clearDfPlayerInput();
boolean waitForTrackFinished(unsigned long timeoutMs);
boolean playTrackAndWait(byte folder, byte file, unsigned long timeoutMs);
void startSelectedMode();
bool trainingAcceptsButton(GameMode mode, int player);
bool trainingNeedsAutomaticReturn(GameMode mode, int ballDirection);
bool trainingServeIsAutomatic(GameMode mode, int player);
boolean buttonBounce(byte button, byte bounceTime);
void game();
void InitializePlayers();
void GameLoop();
void CheckButtons();
void CheckButtonPressedPosition();
void ChangeDirection();
int chooseTrainingHitPosition();
void prepareTrainingReturn();
void performTrainingReturn();
void resetRallyeRound();
void updateRallyeAfterReturn();
void flashRallyeShrink(int oldZoneSize);
void CheckScore();
void CheckWinner();
void GeneratePlayField(byte bright);
void GenerateEndZone();
void GenerateScore(int bright);
void GenerateLastHit();
void BlinkNewScore(int pos, byte color);
void winRainbow(boolean won);
void Rainbow();
void dfpExecute(byte CMD, byte Par1, byte Par2);

//---------------
void setup() {
  Serial.begin(115200);                 // for Debug
  mySerial.begin(9600);                 // for mp3 Player
  delay(500);
  Serial.println();
  Serial.println(F("1D PONG GAME"));

  dfpExecute(0x3F, 0x00, 0x00);       	// Send request to mp3 for initialization parameters
  while (mySerial.available() < 10) {    // Wait until initialization parameters are received
    delay(30);
  }

  delay(300);                            // Let the DFPlayer finish its internal startup
  clearDfPlayerInput();
  updateVolume(true);                    // Set initial potentiometer volume reliably
  Serial.println("Setup Init OK");

  randomSeed(analogRead(0));          	// better random start
  
  FastLED.addLeds<NEOPIXEL, DATA_PIN>(leds, NUM_LEDS);    // FastLed definition

  pinMode(playerBtnPin[0], INPUT_PULLUP); // PINs for buttons
  pinMode(playerBtnPin[1], INPUT_PULLUP);

  for (byte i = 0; i < MODE_COUNT; i++) {
    pinMode(modePins[i], INPUT_PULLUP);
  }

  delay(20);
  GameMode initialMode = readModeSwitchRaw();
  if (initialMode != MODE_INVALID) {
    selectedMode = initialMode;
  }
  modeCandidate = selectedMode;
  modeCandidateSince = millis();
  applyModeSettings(selectedMode);

  playerStart = random(2);                // random starting player
  Serial.println(playerStart);
  Serial.println(" Spieler beginnt");
  Rainbow();                              // color effect

  // Startup order is deliberately strict: greeting, instructions, selected mode.
  // Clear any old DFPlayer status frame before the first spoken file.
  updateVolume(true);
  clearDfPlayerInput();
  delay(150);

  playTrackAndWait(0x01, 10, START_TRACK_TIMEOUT_MS);  // 010.mp3: greeting FIRST
  delay(150);
  clearDfPlayerInput();

  playTrackAndWait(0x01, 11, START_TRACK_TIMEOUT_MS);  // 011.mp3: brightness/start instructions
  delay(150);
  clearDfPlayerInput();

  announceMode(selectedMode);             // 020..024 only after 011 has finished
}

// *********************************
void loop() {
  updateVolume();                         // allow volume adjustment while idle
  updateModeSelection();                  // accept a stable new rotary-switch position

  if (brightSet) {
    GeneratePlayField(brightness);        // show play-field
    FastLED.show();

    // set brightness (button player 0)
    if (buttonBounce(0, 5) == true) {
      brightness += 50;
      if (brightness > 255) {
        brightness = 55;
      }
      Serial.print(F("brightness "));
      Serial.println(brightness);
      GeneratePlayField(brightness);
      FastLED.show();

      while (buttonBounce(0, 5) == true) {}   // wait for button release
    }
  }

  if (buttonBounce(1, 5) == true) {       // confirm/start selected mode
    while (buttonBounce(1, 5) == true) {} // wait for button release
    startSelectedMode();
  }
}

//---------------
GameMode readModeSwitchRaw() {
  byte activeContacts = 0;
  GameMode detectedMode = MODE_INVALID;

  for (byte i = 0; i < MODE_COUNT; i++) {
    if (digitalRead(modePins[i]) == LOW) {
      activeContacts++;
      detectedMode = (GameMode)i;
    }
  }

  // During switching, a rotary switch may briefly connect none or two contacts.
  // Keep the previous mode until exactly one valid contact is active.
  return activeContacts == 1 ? detectedMode : MODE_INVALID;
}

//---------------
void updateModeSelection() {
  GameMode rawMode = readModeSwitchRaw();

  if (rawMode == MODE_INVALID) {
    modeCandidate = MODE_INVALID;
    return;
  }

  if (rawMode != modeCandidate) {
    modeCandidate = rawMode;
    modeCandidateSince = millis();
    return;
  }

  if (rawMode != selectedMode && millis() - modeCandidateSince >= MODE_DEBOUNCE_MS) {
    selectedMode = rawMode;
    applyModeSettings(selectedMode);
    if (selectedMode == MODE_TRAINING) {
      playerStart = random(2);             // random first serve when entering Training
    }
    memset(playerScore, 0, sizeof(playerScore));
    previousButtonPos = -1;
    activeGame = false;
    brightSet = true;

    FastLED.clear();
    FastLED.show();

    // Stop any previous announcement/special-mode sound first. Some DFPlayer
    // clones otherwise swallow the immediately following play command.
    dfpExecute(0x16, 0x00, 0x00);
    delay(150);
    clearDfPlayerInput();
    announceMode(selectedMode);
  }
}

//---------------
void applyModeSettings(GameMode mode) {
  // Values remain expressed in the original 60-LED reference units and are
  // scaled to the installed 144-LED strip below.
  PongModeConfig config = pongModeConfigFor(mode);
  gameSpeedMin = config.startSpeed;
  gameSpeedStep = config.speedStep;
  ballSpeedMax = config.fastestSpeed;
  ballBoost0 = config.boost0;
  ballBoost1 = config.boost1;
  ballBoost2 = config.boost2;
  endZoneSize = ((long)config.endZoneBase * NUM_LEDS + BASE_NUM_LEDS / 2) / BASE_NUM_LEDS;
  rallyeStartEndZoneSize = endZoneSize;
  rallyeMinimumEndZoneSize =
      ((long)RALLYE_MIN_END_ZONE_BASE * NUM_LEDS + BASE_NUM_LEDS / 2) / BASE_NUM_LEDS;
  rallyeShrinkStep =
      ((long)RALLYE_SHRINK_STEP_BASE * NUM_LEDS + BASE_NUM_LEDS / 2) / BASE_NUM_LEDS;
  rallyeSuccessfulReturns = 0;

  Serial.print(F("mode "));
  Serial.print((byte)mode + 1);
  Serial.print(F(", startSpeed "));
  Serial.print(gameSpeedMin);
  Serial.print(F(", endZone LEDs "));
  Serial.println(endZoneSize);
}

//---------------
void clearDfPlayerInput() {
  while (mySerial.available() > 0) {
    mySerial.read();
  }
}

//---------------
// Wait for the DFPlayer's unsolicited "track finished" frame.
// Command 0x3D is TF-card playback finished; 0x3C is USB playback finished.
// Volume changes remain possible while waiting. A timeout prevents lockups if
// a clone does not emit the completion frame.
boolean waitForTrackFinished(unsigned long timeoutMs) {
  byte frame[10];
  byte frameIndex = 0;
  unsigned long startedAt = millis();

  while ((unsigned long)(millis() - startedAt) < timeoutMs) {
    updateVolume();

    while (mySerial.available() > 0) {
      byte value = mySerial.read();

      // Re-synchronise strictly on the DFPlayer start byte.
      if (frameIndex == 0) {
        if (value != 0x7E) {
          continue;
        }
        frame[frameIndex++] = value;
        continue;
      }

      // A new start byte inside an incomplete frame begins a fresh frame.
      if (value == 0x7E) {
        frame[0] = value;
        frameIndex = 1;
        continue;
      }

      frame[frameIndex++] = value;

      if (frameIndex == sizeof(frame)) {
        frameIndex = 0;

        uint16_t receivedChecksum = ((uint16_t)frame[7] << 8) | frame[8];
        uint16_t calculatedChecksum = -(frame[1] + frame[2] + frame[3] +
                                        frame[4] + frame[5] + frame[6]);

        boolean validFrame = frame[0] == 0x7E &&
                             frame[1] == 0xFF &&
                             frame[2] == 0x06 &&
                             frame[9] == 0xEF &&
                             receivedChecksum == calculatedChecksum;

        if (validFrame && (frame[3] == 0x3D || frame[3] == 0x3C)) {
          return true;
        }
      }
    }

    delay(5);
  }

  Serial.println(F("DFPlayer: track-finished timeout"));
  return false;
}

//---------------
boolean playTrackAndWait(byte folder, byte file, unsigned long timeoutMs) {
  clearDfPlayerInput();
  dfpExecute(0x0F, folder, file);
  return waitForTrackFinished(timeoutMs);
}

//---------------
void announceMode(GameMode mode) {
  int track = modeAnnouncementTrack(mode);
  if (track > 0) {
    dfpExecute(0x0F, 0x01, track);
  }
}

//---------------
void startSelectedMode() {
  applyModeSettings(selectedMode);
  brightSet = false;

  activeGame = true;
  dfpExecute(0x0F, 0x01, 1);            // game start sound
  game();

  activeGame = false;
  brightSet = true;
}


//---------------

//---------------

//---------------

//---------------


//---------------
// Read a 10k potentiometer on A1 and set DFPlayer volume (1 ... 20).
// The value is checked only every 200 ms and transmitted only when the
// resulting volume step changes, preventing unnecessary serial commands.
void updateVolume(boolean forceUpdate) {
  if (!forceUpdate && millis() - previousVolumeMillis < 200) {
    return;
  }

  previousVolumeMillis = millis();

  // Five readings reduce ADC noise.
  long rawSum = 0;

  for (byte i = 0; i < 5; i++) {
    rawSum += analogRead(VOLUME_PIN);
    delayMicroseconds(200);
  }

  int rawValue = rawSum / 5;
  byte newVolume = map(rawValue, 0, 1023, VOLUME_MIN, VOLUME_MAX);

  // Set the initial volume immediately.
  if (forceUpdate) {
    volumeLevel = newVolume;
    previousVolumeLevel = newVolume;
    pendingVolumeLevel = newVolume;
    pendingVolumeCount = 0;

    dfpExecute(0x06, 0x00, volumeLevel);

    Serial.print(F("volume "));
    Serial.println(volumeLevel);
    return;
  }

  // Nothing changed.
  if (newVolume == previousVolumeLevel) {
    pendingVolumeLevel = newVolume;
    pendingVolumeCount = 0;
    return;
  }

  // First occurrence of a possible new value.
  if (newVolume != pendingVolumeLevel) {
    pendingVolumeLevel = newVolume;
    pendingVolumeCount = 1;
    return;
  }

  // Accept only after two consecutive identical measurements.
  pendingVolumeCount++;

  if (pendingVolumeCount >= 2) {
    volumeLevel = newVolume;
    previousVolumeLevel = newVolume;
    pendingVolumeCount = 0;

    dfpExecute(0x06, 0x00, volumeLevel);

    Serial.print(F("volume "));
    Serial.println(volumeLevel);
  }
}


//---------------
// function to debounce button (true == pressed, false == not pressed)
boolean buttonBounce(byte button, byte bounceTime) {       
  boolean result = false;
  if (digitalRead(playerBtnPin[button]) == LOW) {
    delay (bounceTime);
    if (digitalRead(playerBtnPin[button]) == LOW) {
      result = true;
    }
  }
  return result;
}

// ============================================================================
// Modus-Hilfsfunktionen: Training und Rallye
// ============================================================================

bool trainingAcceptsButton(GameMode mode, int player) {
  return mode != MODE_TRAINING || player == TRAINING_HUMAN_PLAYER;
}

bool trainingNeedsAutomaticReturn(GameMode mode, int ballDirection) {
  return mode == MODE_TRAINING && ballDirection == -1;
}

bool trainingServeIsAutomatic(GameMode mode, int player) {
  return mode == MODE_TRAINING && player == TRAINING_ARDUINO_PLAYER;
}

bool trainingShouldMiss(long randomRoll, int missInterval) {
  return missInterval > 0 && randomRoll == 0;
}

int rallyeZoneSize(int startZoneSize,
                          int minimumZoneSize,
                          int shrinkStep,
                          int returnsPerShrink,
                          int successfulReturns) {
  if (returnsPerShrink <= 0 || shrinkStep <= 0 || successfulReturns <= 0) {
    return startZoneSize;
  }

  int shrinkStages = successfulReturns / returnsPerShrink;
  int zoneSize = startZoneSize - shrinkStages * shrinkStep;
  return zoneSize < minimumZoneSize ? minimumZoneSize : zoneSize;
}

bool rallyeShouldFlash(int successfulReturns,
                              int returnsPerShrink,
                              int currentZoneSize,
                              int minimumZoneSize) {
  return returnsPerShrink > 0 &&
         successfulReturns > 0 &&
         successfulReturns % returnsPerShrink == 0 &&
         currentZoneSize > minimumZoneSize;
}
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

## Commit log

2026-08-06 Add files via upload
    Initial release
    [LEDPong-Endkappe-60x40.stl, LEDPong-Endkappe-mit-USB-60x40.stl, LEDStrip-Abdeckkappe.stl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]
2026-08-06 Add image to LEDPong setup instructions
2026-08-07 Update README for LEDPong sketch version change
2026-08-07 Update mode descriptions for rotary switch connections
2026-08-07 Update LEDPong sketch version in instructions
2026-08-07 Clarify mode selection switch description in README
    Updated the description of the mode selection switch for clarity.
2026-08-07 Add LEDPong_v1.1.0.ino file
2026-08-07 Update LEDPong version in README
2026-08-10 Update LEDPong images in Aufbauanleitung.md
2026-08-10 Update image order in Aufbauanleitung.md
    Rearranged images in the LEDPong documentation.
2026-08-10 Update README with LEDPong images and description
    Added images and section for finished LEDPong.
2026-08-10 support multiple color-buttons
2026-08-10 Update README with alternative button audio files
    Added alternative button color audio files with descriptions.
2026-08-10 Restore alternative hint files and usage instructions
    Restored alternative hint files section for button colors and usage instructions.
2026-08-10 Update README with alternative audio file details
    Added alternative audio files for different button colors.
2026-08-10 Update README with player color customization details
    Added section on player color customization for LEDPong.
2026-08-10 Fix directory name for alternative button colors
    Corrected the directory name for alternative audio announcements.
2026-08-10 Revise alternative colors usage instructions
    Updated instructions for using alternative button colors and player colors in the README.
2026-08-10 Update README to remove LED color adjustment note
    Remove instruction to adjust player LED colors in code.
2026-08-10 Update README with LEDPong images and description
    Added images and description for the finished LEDPong.
2026-08-10 Enhance LEDPong image captions in Anleitung
    Added descriptions for LEDPong images in the documentation.
2026-08-10 Enhance assembly instructions for cover fixation
    Added instructions for securing the cover with tape.
2026-08-11 Include unit prices in Stückliste
    Added individual prices for components in the bill of materials.
2026-08-14 Add image for LEDPong components preparation
    Added an image reference for LEDPong components.
2026-08-14 Change LEDPong components image from PNG to JPG
    Updated image format for LEDPong components in the guide.
